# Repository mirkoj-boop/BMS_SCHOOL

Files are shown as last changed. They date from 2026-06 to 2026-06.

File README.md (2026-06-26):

# BMS  4S Li-Ion Battery Management System

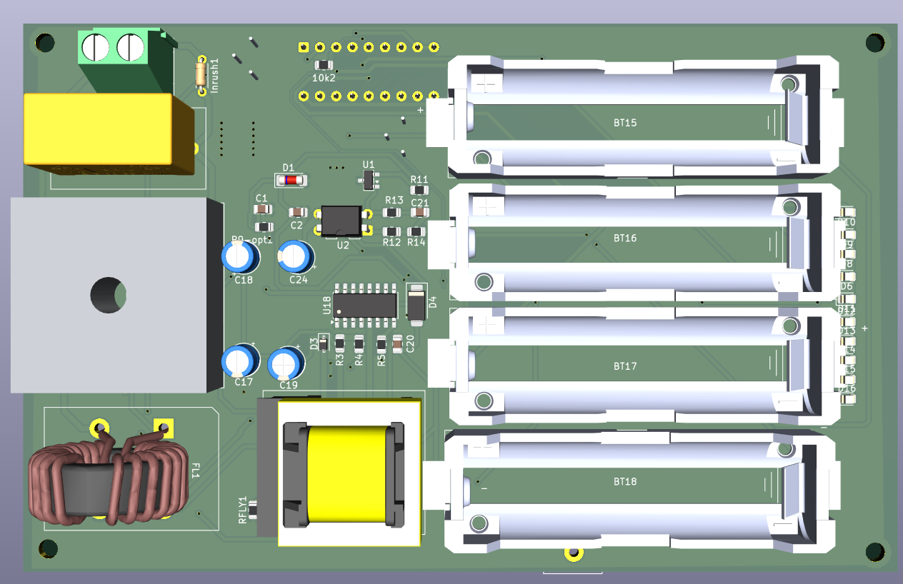
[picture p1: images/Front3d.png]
Front 3D view


> BMS PCB designed in KiCad for a 4S Li-Ion battery pack integrates cell protection, passive balancing, isolated AC/DC charging, and LED battery indication on a single board.

---

## Features

- **4S Li-Ion protection** via BQ77905 - OVP, UVP, OCD, SCD, OT/UT per cell
- **Passive cell balancing** (VC1–VC5)
- **Isolated flyback AC/DC charger** - VIPer26LD + PC817 + TL431 feedback
- **10-segment LED battery indicator** - LM3914
- **AC EMI filter** - X+Y capacitors, varistor surge protection
- **Temperature monitoring** - NTC thermistor on TS pin

---

## Specifications

| Parameter | Value |
|---|---|
| Cell configuration | 4S Li-Ion |
| Nominal pack voltage | 14.4 V |
| Full charge voltage | 16.8 V |
| Charge current | 2 A |
| Charger input |230V(50Hz) |
| Design tool | KiCad 10 |

---

## Key Components

| Reference | Part | Function |
|---|---|---|
| U21 | BQ77905 | BMS IC - protection + balancing |
| U18 | VIPer26LD | Flyback AC/DC controller |
| U3 | LM3914 | LED battery level indicator |
| U2 | PC817 | Optocoupler - galvanic isolation |
| U1 | TL431DBZ | Voltage reference - feedback |
| T3 | Würth EE20_10_6_750811647 | Flyback transformer |
| Q22, Q23 | CSD19531Q5A | N-ch MOSFETs - charge/discharge path |
| D2 | KBPC | AC bridge rectifier |
| FL2 | P300PL104M275xC332 | AC EMI filter |
| RV01 | Varistor | Surge/overvoltage protection |
| TH2 | Thermistor | Temperature sense (TS pin) |

---

## System Architecture

```
230V(50Hz) ──► FL2 (EMI filter) ──► D2 (rectifier) ──► U18 VIPer26LD
                                                              │
                                                         T3 transformer
                                                        ╱             ╲
                                               Aux winding         Secondary
                                                    │                   │
                                               VDD (~5V)           VO (16.8V)
                                                                        │
                                                              PC817 + TL431
                                                             (isolated feedback)

4S Pack (BT15–BT18) ──► BQ77905 ──► CSD19531Q5A MOSFETs ──► PACK+ / PACK-
                              │
                          LM3914 ──► LED bar
```

## References

- [TI SLUA793 — BQ77905 Design Considerations in High-Current Applications](https://www.ti.com/lit/an/slua793/slua793.pdf)
- [DigiKey Reference Design — AC/DC SMPS Multi-Output (STEVAL-ISA081V1)](https://www.digikey.com/reference-designs/en/ac-dc-and-dc-dc-conversion/ac-dc-smps-multi-output/752)
- [EEVblog — How Does This Flyback Feedback Circuit Work?](https://www.eevblog.com/forum/projects/how-does-this-flyback-feedback-circuit-work/)
- [BQ77905 Product Page — Texas Instruments](https://www.ti.com/product/BQ77905)
- [VIPer26LD Datasheet — STMicroelectronics](https://www.st.com/en/power-management/viper26ld.html)

---

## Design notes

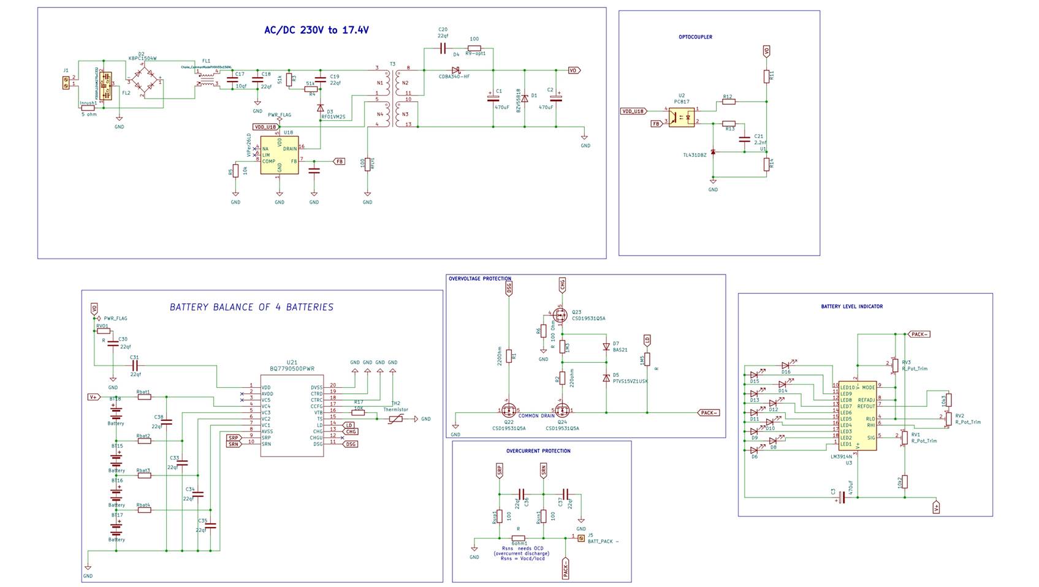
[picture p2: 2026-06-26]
images/schematic.jpg

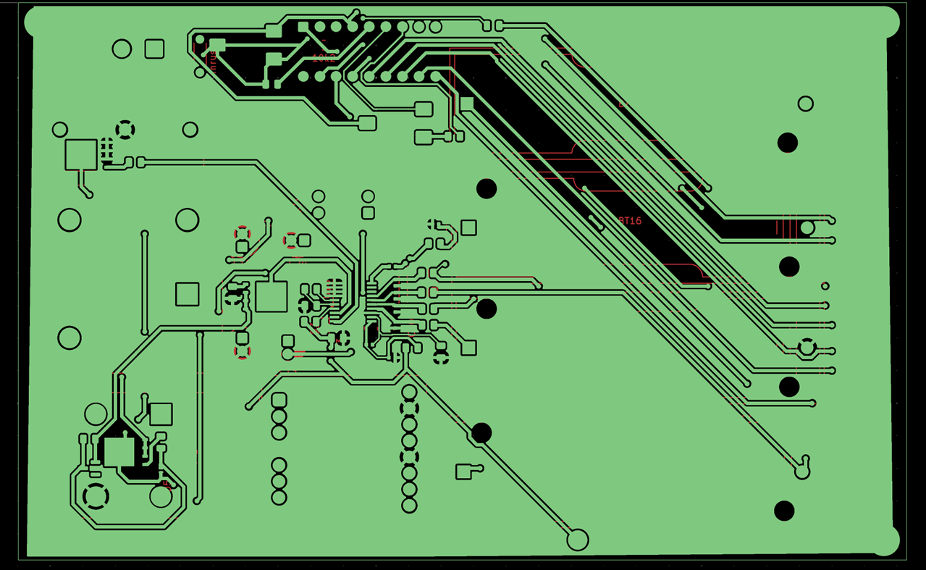
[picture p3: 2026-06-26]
images/BackCu.png

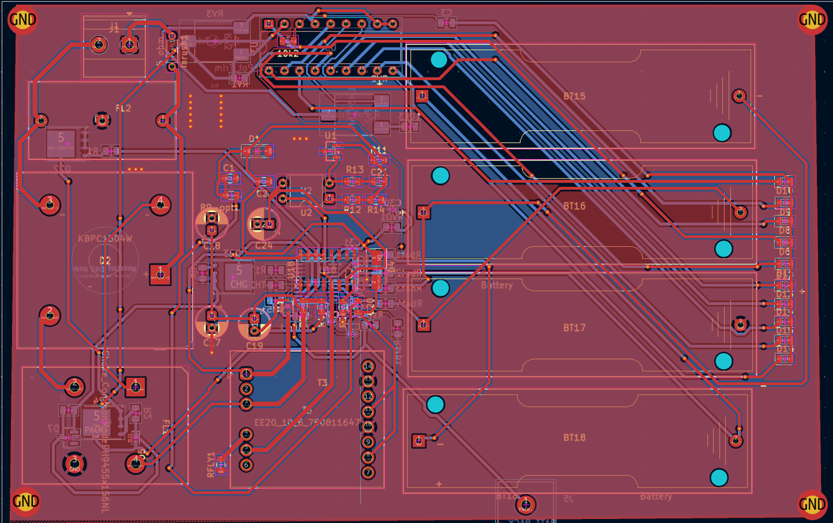
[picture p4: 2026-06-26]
images/FrontCU.png

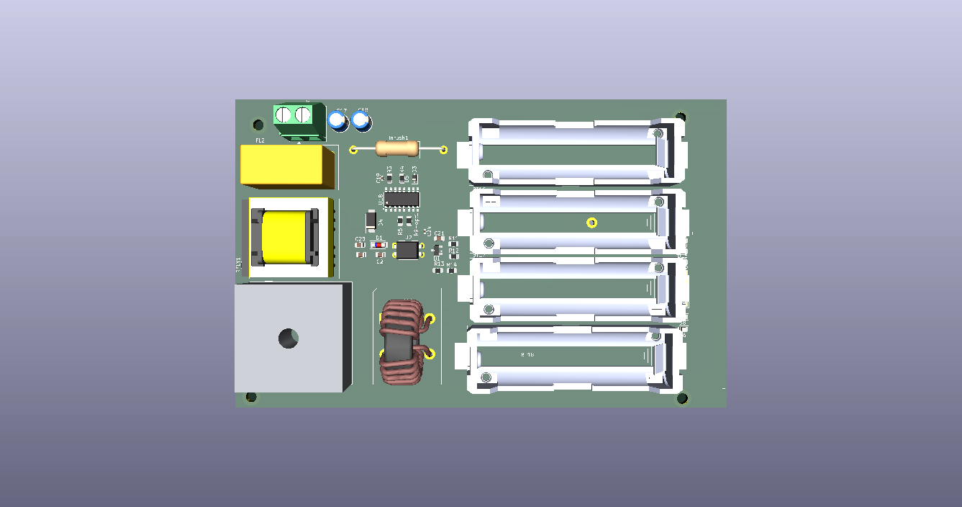
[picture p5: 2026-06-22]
BMS.png

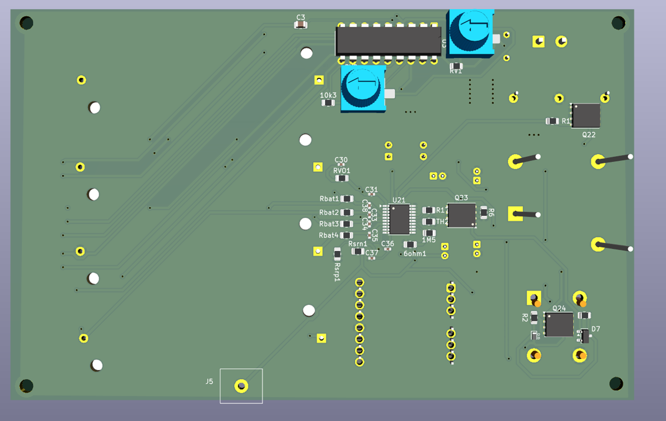
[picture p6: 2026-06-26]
images/Back3d.png

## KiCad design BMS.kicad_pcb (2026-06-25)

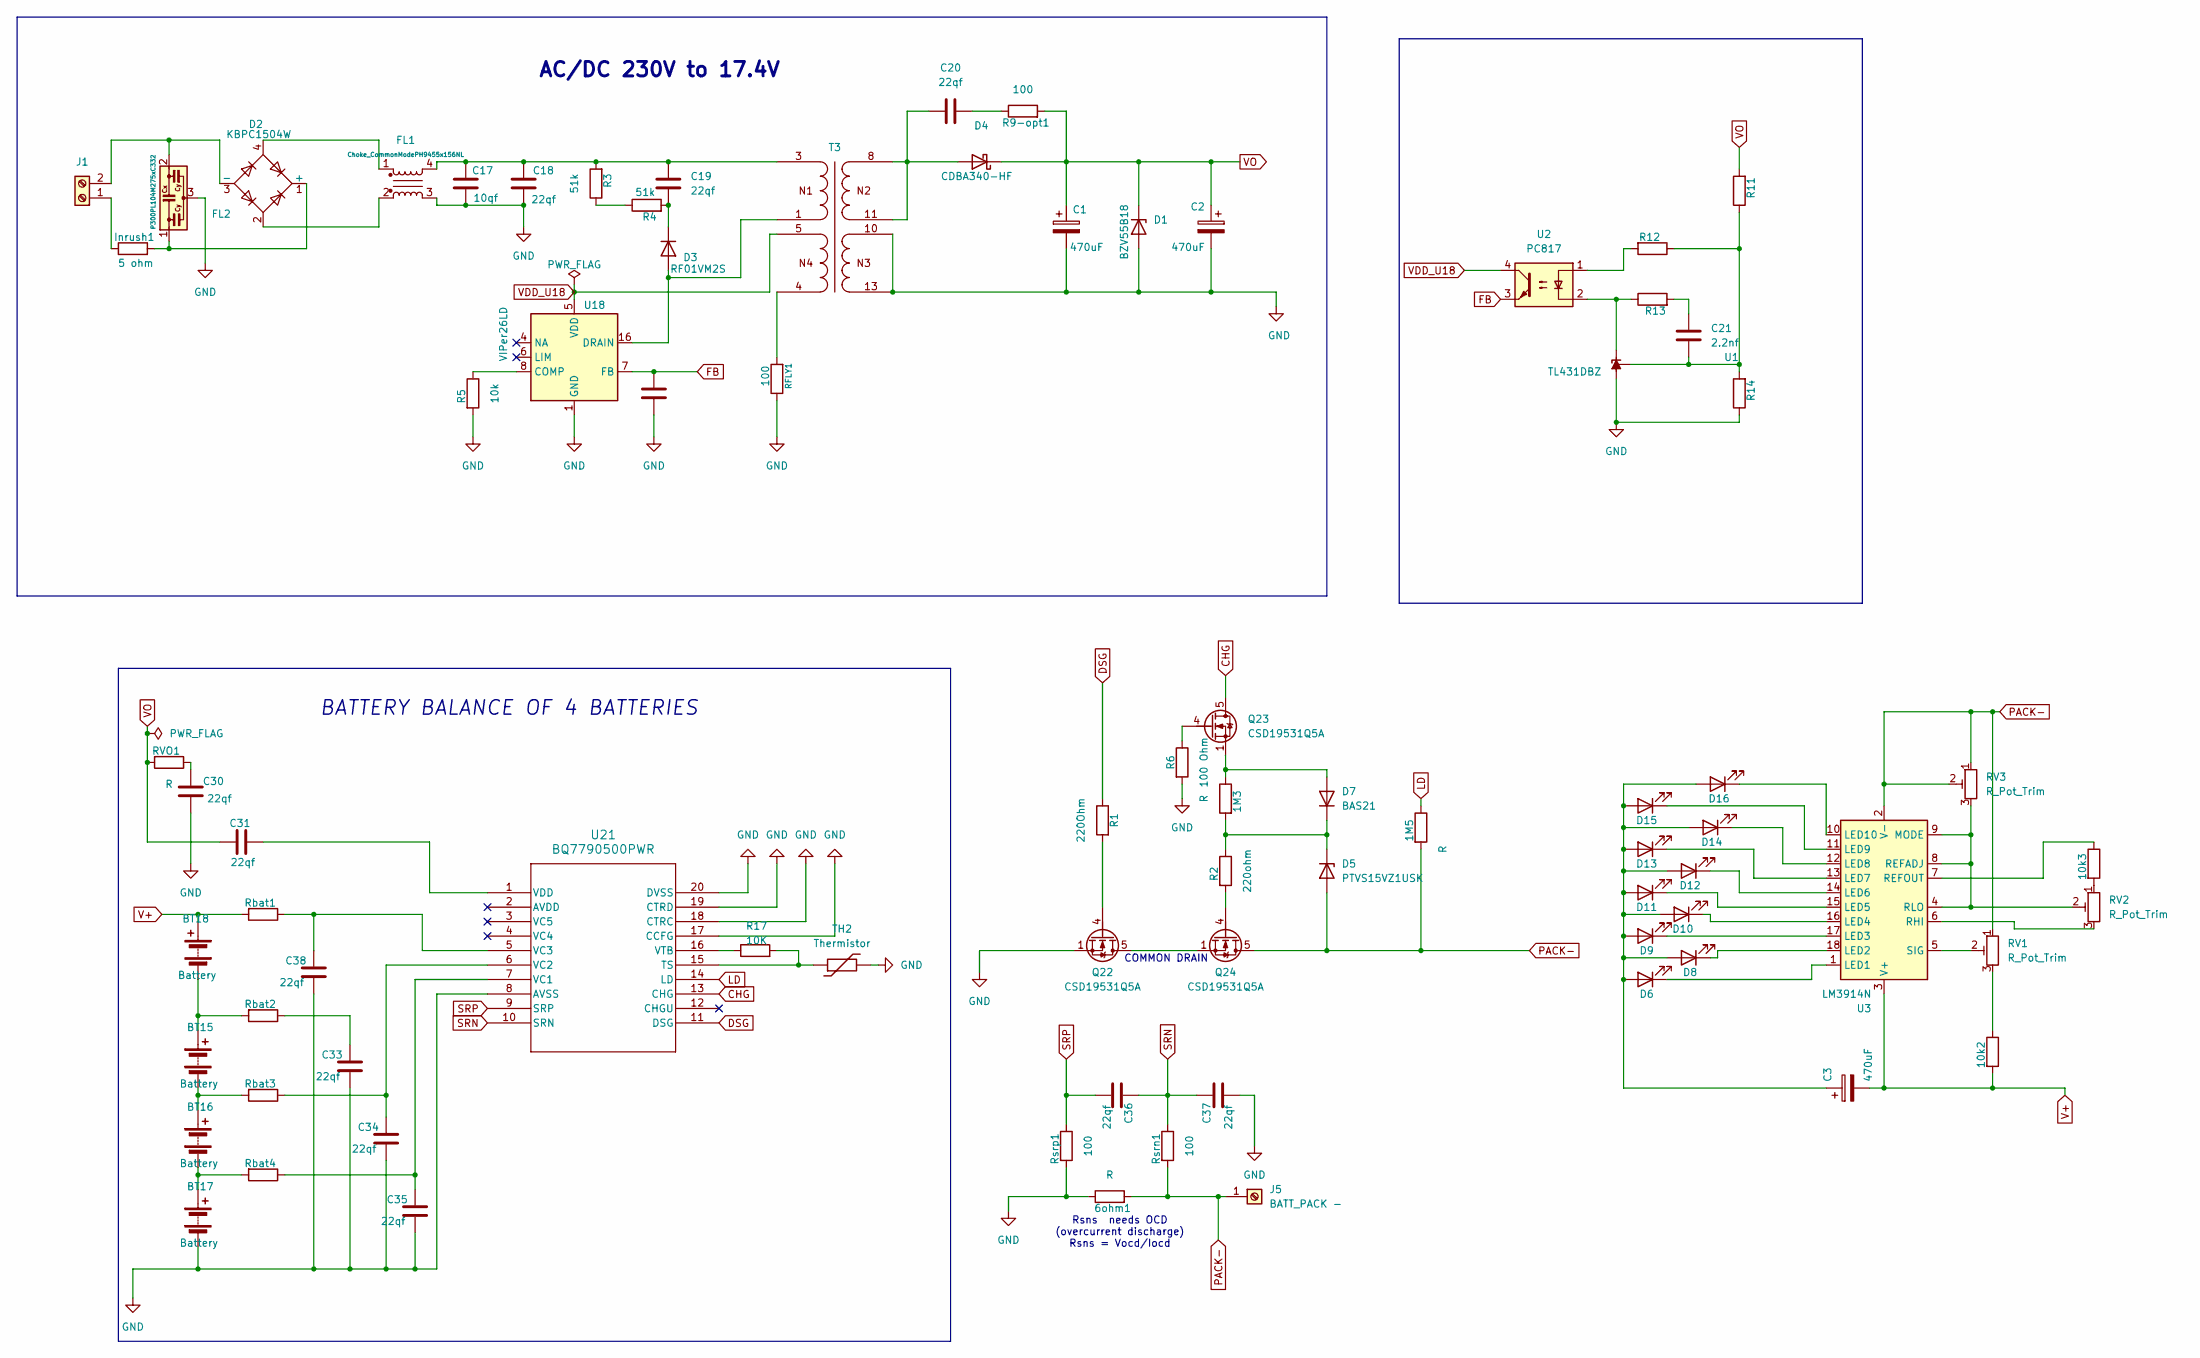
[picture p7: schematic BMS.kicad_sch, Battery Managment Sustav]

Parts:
1M3, 1M5, 6ohm1: R; R_0805_2012Metric
10k2, 10k3: 10k; R_0805_2012Metric
BT15, BT16, BT17, BT18: Battery; BatteryHolder_Keystone_2460_1xAA
C1, C2, C3: 470uF; C_0805_2012Metric
C17: 10qf; CP_Radial_D5.0mm_P2.00mm
C18, C19: 22qf; CP_Radial_D5.0mm_P2.00mm
C20: 22qf; C_0805_2012Metric
C21: 2.2nf; C_0805_2012Metric
C24: 4.7nF; CP_Radial_D5.0mm_P2.00mm
C30, C31, C33, C34, C35, C36, C37, C38: 22qf; C_0402_1005Metric
D1: BZV55B18; D_MiniMELF
D2: KBPC1504W; Diode_Bridge_GeneSiC_KBPC_W
D3: RF01VM2S; D_SOD-323
D4: CDBA340-HF; D_SMA
D5: PTVS15VZ1USK; Nexperia_DSN1608-2_1.6x0.8mm
D6, D8, D9, D10, D11, D12, D13, D14, D15, D16: LED; LED_0805_2012Metric
D7: BAS21; SOT-23
FL1: Choke_CommonModePH9455x156NL; L_CommonMode_PulseElectronics_PH9455xxx6NL_2
FL2: P300PL104M275xC332; Filter_KEMET_PZB300_24.0x12.5mm_P10.0mm
Inrush1: 5 ohm; R_Axial_DIN0204_L3.6mm_D1.6mm_P5.08mm_Horizontal
J1: Screw_Terminal_01x02; TerminalBlock_Phoenix_MKDS-1,5-2_1x02_P5.00mm_Horizontal
J5: BATT_PACK -; TerminalBlock_MetzConnect_360271_1x01_Horizontal_ScrewM3.0_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
Q22, Q23, Q24: CSD19531Q5A; TDSON-8-1
R1: 220Ohm; R_0805_2012Metric
R2: 220ohm; R_0805_2012Metric
R3, R4: 51k; R_0805_2012Metric
R5: 10k; R_0805_2012Metric
R6: 100 Ohm; R_0805_2012Metric
R9-opt1: 100; R_0805_2012Metric
R11, R12, R13, R14: R; R_0805_2012Metric
R17: 10K; R_0805_2012Metric
RFLY1: 100; R_0805_2012Metric
RV1: R_Pot_Trim; R_0805_2012Metric
RV2, RV3: R_Pot_Trim; Potentiometer_ACP_CA6-VSMD_Vertical
RVO1: R; R_0805_2012Metric
Rbat1, Rbat2, Rbat3, Rbat4: 1k; R_0805_2012Metric
Rsrn1: 100; R_0805_2012Metric
Rsrp1: 100; R_0805_2012Metric
T3: EE20_10_6_750811647; Transformer_Wuerth_760871131; Part Number 750811647
TH2: Thermistor; R_0805_2012Metric
U1: TL431DBZ; SOT-23
U2: PC817; DIP-4_W7.62mm
U3: LM3914N; DIP-18_W7.62mm
U18: VIPer26LD; SOIC-16_3.9x9.9mm_P1.27mm
U21: BQ7790500PWR; TSSOP-20_4.4x6.5mm_P0.65mm

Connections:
CHG: Q23.5 (D), U21.13 (CHG)
DSG: R1.1, U21.11 (DSG)
FB: C24.1, U2.3, U18.7 (FB)
GND: 6ohm1.1, BT17.2 (-), C1.2, C2.2, C17.2, C18.2, C24.2, C30.1, C33.1, C34.1, C35.1, C37.1, C38.1, D1.2 (A), FL1.3, FL2.3, Q22.1 (S), Q22.2 (S), Q22.3 (S), R5.2, R6.2, R14.1, RFLY1.1, Rsrp1.2, T3.10, T3.13, TH2.2, U1.3 (A), U18.1 (GND), U18.2 (GND), U21.8 (AVSS), U21.17 (CCFG), U21.18 (CTRC), U21.19 (CTRD), U21.20 (DVSS)
LD: 1M5.1, U21.14 (LD)
unnamed: 10k2.1, RV1.3
unnamed: 10k3.2, RV2.1
unnamed: BT15.1 (+), BT18.2 (-), Rbat2.2
unnamed: BT15.2 (-), BT16.1 (+), Rbat3.2
unnamed: BT16.2 (-), BT17.1 (+), Rbat4.2
unnamed: C17.1, C18.1, C19.1, FL1.4, R3.2, T3.3
unnamed: C20.1, R9-opt1.1
unnamed: C21.2, R13.2
unnamed: C30.2, RVO1.1
unnamed: C33.2, Rbat2.1
unnamed: D2.1 (+), FL2.1, Inrush1.2
unnamed: D2.3 (-), FL2.2, J1.2
unnamed: D2.2, FL1.2
unnamed: D2.4, FL1.1
unnamed: D3.2 (A), T3.1, U18.13 (DRAIN), U18.14 (DRAIN), U18.15 (DRAIN), U18.16 (DRAIN)
unnamed: C19.2, D3.1 (K), R4.2
unnamed: C20.2, D4.2 (A), T3.8, T3.11
unnamed: 1M3.2, D5.1 (K), D7.3 (K), R2.1
unnamed: D6.1 (K), U3.1 (LED1)
unnamed: 1M3.1, D7.1 (A), Q23.1 (S), Q23.2 (S), Q23.3 (S)
unnamed: D8.1 (K), U3.18 (LED2)
unnamed: D9.1 (K), U3.17 (LED3)
unnamed: C3.1, D6.2 (A), D8.2 (A), D9.2 (A), D10.2 (A), D11.2 (A), D12.2 (A), D13.2 (A), D14.2 (A), D15.2 (A), D16.2 (A)
unnamed: D10.1 (K), U3.16 (LED4)
unnamed: D11.1 (K), U3.15 (LED5)
unnamed: D12.1 (K), U3.14 (LED6)
unnamed: D13.1 (K), U3.13 (LED7)
unnamed: D14.1 (K), U3.12 (LED8)
unnamed: D15.1 (K), U3.11 (LED9)
unnamed: D16.1 (K), U3.10 (LED10)
unnamed: Inrush1.1, J1.1
unnamed: Q22.5 (D), Q24.1 (S), Q24.2 (S), Q24.3 (S)
unnamed: Q22.4 (G), R1.2
unnamed: Q23.4 (G), R6.1
unnamed: Q24.4 (G), R2.2
unnamed: R3.1, R4.1
unnamed: R12.2, U2.1
unnamed: RFLY1.2, T3.4
unnamed: R13.1, U1.1 (K), U2.2
unnamed: C21.1, R11.1, R12.1, R14.2, U1.2 (REF)
unnamed: RV2.2, RV3.3, U3.4 (RLO), U3.8 (REFADJ), U3.9 (MODE)
unnamed: 10k3.1, U3.7 (REFOUT)
unnamed: RV2.3, U3.6 (RHI)
unnamed: RV1.2, U3.5 (SIG)
unnamed: R5.1, U18.8 (COMP)
unnamed: R17.2, TH2.1, U21.15 (TS)
unnamed: C35.2, Rbat4.1, U21.7 (VC1)
unnamed: C34.2, Rbat3.1, U21.6 (VC2)
unnamed: C38.2, Rbat1.1, U21.5 (VC3)
unnamed: C31.2, U21.1 (VDD)
unnamed: R17.1, U21.16 (VTB)
PACK-: 1M5.2, 6ohm1.2, D5.2 (A), J5.1 (Pin_1_1), Q24.5 (D), RV1.1, RV3.1, RV3.2, Rsrn1.2, U3.2 (V-)
SRN: C36.2, C37.2, Rsrn1.1, U21.10 (SRN)
SRP: C36.1, Rsrp1.1, U21.9 (SRP)
V+: 10k2.2, BT18.1 (+), C3.2, Rbat1.2, U3.3 (V+)
VDD_U18: T3.5, U2.4, U18.5 (VDD)
VO: C1.1, C2.1, C31.1, D1.1 (K), D4.1 (K), R9-opt1.2, R11.2, RVO1.2

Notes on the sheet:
Rsns needs OCD (overcurrent discharge) Rsns = Vocd/Iocd
COMMON DRAIN
AC/DC 230V to 17.4V
BATTERY BALANCE OF 4 BATTERIES

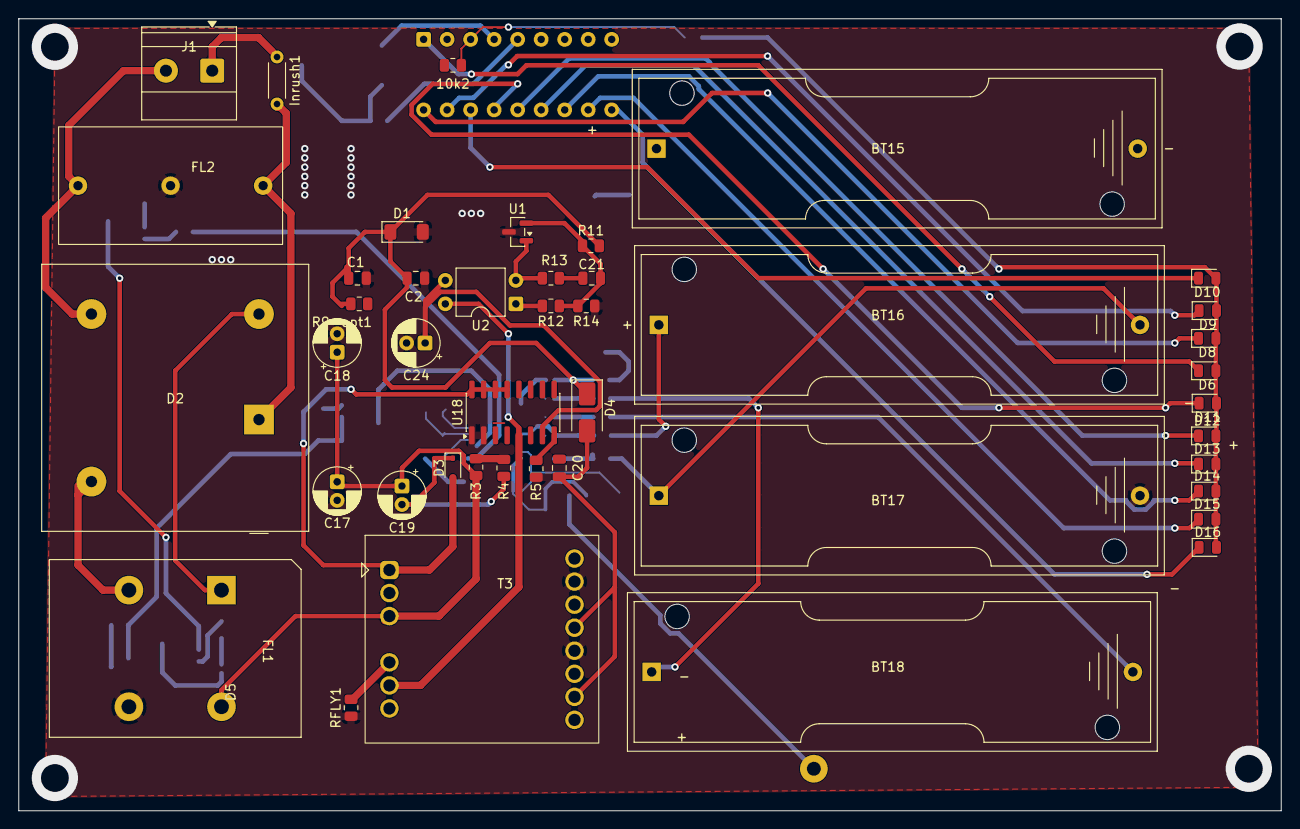
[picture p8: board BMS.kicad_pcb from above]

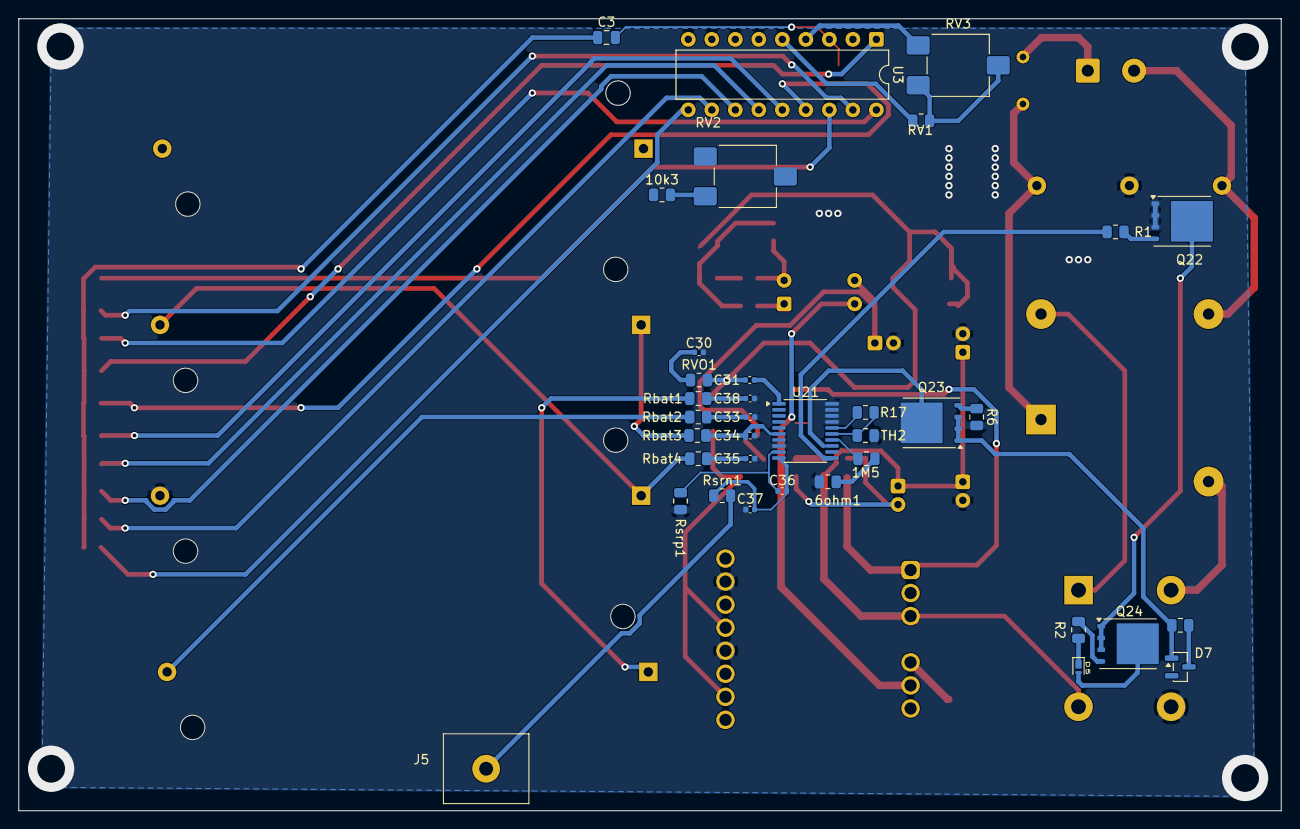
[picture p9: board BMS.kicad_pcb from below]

Board: 2 copper layers, 136.4 x 85.6 mm, 80 parts (36 on the bottom side), 61 nets.

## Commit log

2026-04-26 Lecture Update
    Updated some forms in charging section
    [BMS.kicad_sch, lm317.kicad_sch, untitled.kicad_sch]
2026-05-05 ac dc converter set with flyback transformer
    Preparation for 5V with 12V headers
    [BMS.kicad_sch, lm317.kicad_sch, untitled.kicad_sch]
2026-05-05 Case
    First case commit
    [Part1.SLDPRT]
2026-05-07 Chip decided
    [lm317.kicad_sch]
2026-06-14 flyback transformer
    Flyback transformer fixed along with regulation
    [BMS.kicad_sch, charger.sch.kicad_sch, lm317.kicad_sch]
2026-06-15 Update
    updated Flyback control
    [BMS.kicad_sch]
2026-06-15 update schematic view
    [BMS.kicad_sch, charger.sch.kicad_sch, lm317.kicad_sch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]
2026-06-15 Add BMS backup zip and image
    Add a BMS backup archive and a related image to the repository. Files added: BMS-backups/BMS-2026-06-15_230002.zip (backup archive) and images/bms.jpg (reference image for BMS).
2026-06-15 Rename image to include space before extension
    Rename images/bms.jpg to images/bms .jpg (100% similarity). No content changes—only the filename was changed to include a space before the .jpg extension. Update any references to the image to avoid broken links or import errors.
2026-06-15 Remove backup zips and KiCad lock files
    Delete legacy BMS backup archives and temporary KiCad lock files from the repository to clean up large binary backups and stale editor lock files. Removed files: BMS-backups/BMS-2026-06-14_190508.zip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
2026-06-16 Add AC/DC & balancer sheets; update BMS schematic
    Add new schematic files (acdc, acdcflyback, acdc.sch.kicad_sch, balancer/balance, overcharge, overcurrent) plus autosave copies, a backup zip and KiCad lock files. Update BMS.kicad_pro to register th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
    [BMS.kicad_sch, acdc.sch.kicad_sch, acdcflyback.kicad_sch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]
2026-06-16 Add EMI filter symbol; adjust schematic labels/wiring
    Add two backup ZIPs and update KiCad project/schematic. BMS.kicad_pro: add ngspice config, simplify used_designators and trim sheets list. BMS.kicad_sch: add a new EMI filter symbol (P300PL104M275xC332) with graphics and pins, adjust many wires/junctions/no_connects, reposition and add global labels (FB, VDD, DSG, SRN, VO, CHG), update several power/GND symbols and component references/values/footprints (including renaming inrush resistor and R1), plus other cleanup of instances and UUIDs. These changes prepare the schematic for the EMI component and tidy net labeling/placement.
    [BMS.kicad_sch]
2026-06-19 Add Wurth connector 3D model & footprint
    Add STEP 3D model and footprint for T_Wurth_WE-OLTI-EE20_10_6_750811647 and update KiCad project files. BMS.kicad_pro and BMS.kicad_sch were modified, autosave schematic files removed, and backup ZIP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
    [BMS.kicad_sch, T_Wurth_WE-OLTI-EE20_10_6_750811647.step]
2026-06-21 Add full KiCad PCB file and backups
    Replace the placeholder BMS.kicad_pcb with the complete KiCad PCB data (version 20260206) including layers, setup, footprints, pads and 3D models. Update related project files (BMS.kicad_prl, BMS.kicad_pro, BMS.kicad_sch) and their lock files. Add five new backup archives in BMS-backups (2026-06-19 and multiple 2026-06-20 timestamps).
    [BMS.kicad_pcb, BMS.kicad_sch]
2026-06-21 Battery level indicator LM3914
    [BMS.kicad_sch]
2026-06-22 Update PCB stackup, footprints, and add backups
    Add multiple BMS backup archives and project PNG; modify BMS.kicad_pcb with an explicit stackup (layers, thicknesses, dielectric), enable zone_defaults, and update many footprints and component definitions. Changes include footprint replacements and edits (resistor/pad sizes, SMD 0402→0805 adjustments, pad positions/nets, UUIDs), added/adjusted 3D model references and part rotations/offsets, and new LED/resistor SMD footprints. Also update related KiCad project files and lock files.
    [BMS.kicad_pcb, BMS.kicad_sch]
2026-06-23 Update of routing
    [BMS.kicad_pcb, BMS.kicad_sch]
2026-06-24 Updated GND via and holes
    GND was missdirected at VO point and had to be fixed
    [BMS.kicad_pcb, BMS.kicad_sch]
2026-06-24 Routing update
    [BMS.kicad_pcb, BMS.kicad_sch]
2026-06-24 front layer route
    [BMS.kicad_pcb]
2026-06-25 Routing update
    19 errors to go
    [BMS.kicad_pcb, BMS.kicad_sch]
2026-06-26 Add README for 4S Li-Ion Battery Management System
    Added detailed documentation for the 4S Li-Ion Battery Management System, including features, specifications, key components, system architecture, and references.
2026-06-26 Revise charger input and remove outdated sections
    Updated charger input specification and system architecture diagram. Removed sections on net references, current sensing, output voltage setting, and PCB notes.
2026-06-26 Refine BMS description in README
    Removed 'Custom' from the description for clarity.
